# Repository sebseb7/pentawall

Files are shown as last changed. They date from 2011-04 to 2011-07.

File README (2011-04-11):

************
* pentawall
************

This project aims to build a full-RGB LED-wall with a resolution of at least 15x15 pixels. 

This is done using stackable 5x1 LED modules. (pentawall because its 5 LEDs per module)

I produced 50 of these modules and finished a 15x16 Wall as you can see here: http://vimeo.com/21198058 and http://vimeo.com/21123365

*****
* technical overview
*****

LED MODULE
==========

each module consists of 
- 5 LEDs ( Osram LRTB G6TG )
- 1 LED controller ( Textas Instruments TLC5941 ) 
- 1 microcontroller ( Atmel ATMEGA168pa ) 

The TLC5941 is a 16-channel, constant-current sink, LED driver. Here only 15 channels are in use (5 LEDs * 3 colors).
Each channel has an individually adjustable 4096-step grayscale PWM brightness control and a 64-step constant-current sink (dot correction).
Both grayscale control and dot correction are accessible via a serial interface (SPI).
For grayscale control the atmega has to feed in 24 bytes of data (16 * 12 bit).

The microcontroller receives its data via an i2c bus.

MASTER MODULE
=============

consists of
- atmega644p
- ft232rl

the master module recives data via USB and feeds that data to the led modules via i2c bus.
Using this master any PC with USB can control the LED wall. If you have i2c on you computer you dont need this module.

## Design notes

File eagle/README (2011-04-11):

this folder contains the schematics and board layout files for the hardware

5led.* the LED Module
ledmaster.* the master module (i2c to usb bridge)

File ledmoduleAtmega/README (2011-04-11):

This is the Code for the microcontroller on the X5LED board.

it acts as a i2c slave and receives data over the i2c bus to set led channel brightness

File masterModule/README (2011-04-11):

This is the Code for the microcontroller on the master module

it acts as a uart -> i2c bridge to access the ledmodules via uart

with an ftdi it can be connected to usb

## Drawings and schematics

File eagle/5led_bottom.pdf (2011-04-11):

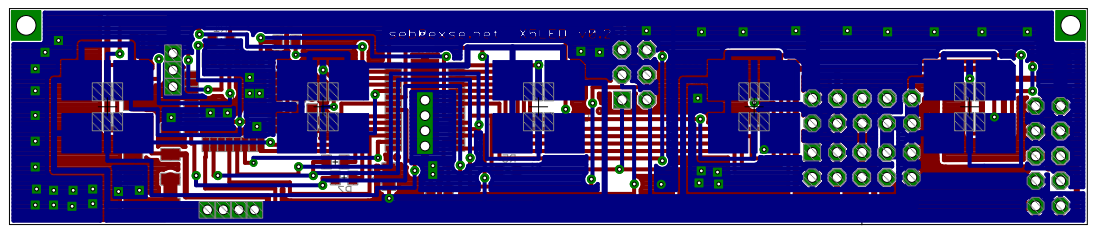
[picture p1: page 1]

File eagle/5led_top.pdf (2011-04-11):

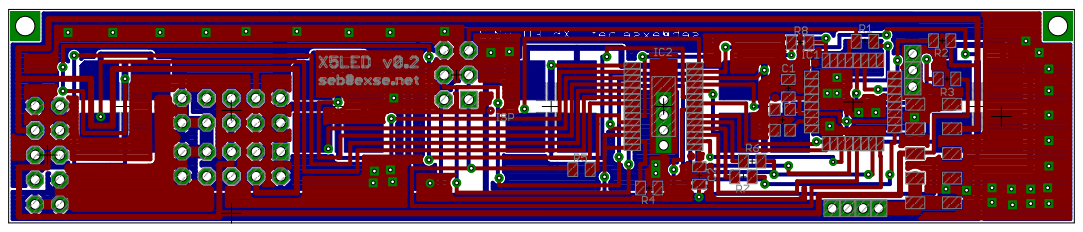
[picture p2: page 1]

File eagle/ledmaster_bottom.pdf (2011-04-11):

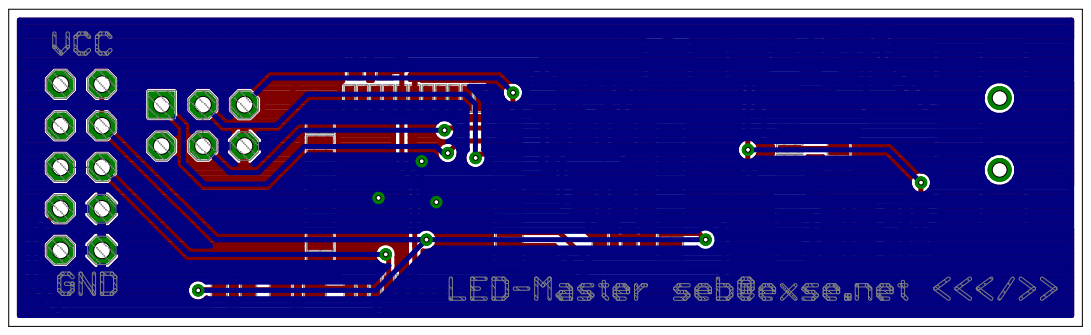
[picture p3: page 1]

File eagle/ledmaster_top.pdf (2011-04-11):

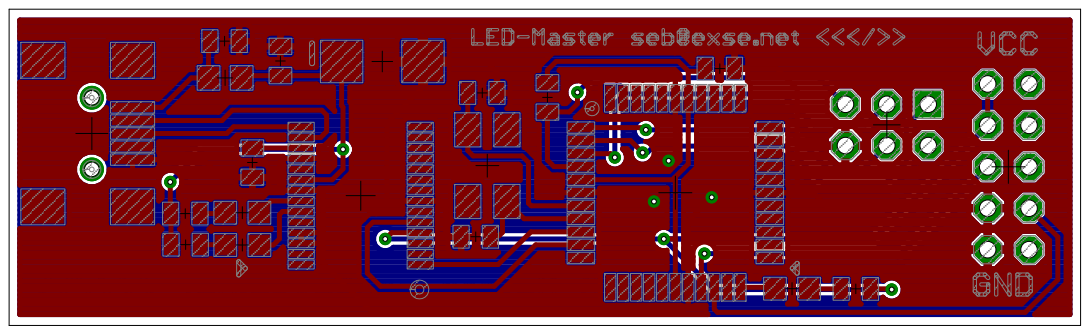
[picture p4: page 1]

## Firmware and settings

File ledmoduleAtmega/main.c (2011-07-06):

#include <inttypes.h>
#include <avr/io.h>
#include <avr/interrupt.h>
#include <avr/eeprom.h>
#include <util/delay.h>

#include "main.h"
#include "timer.h"
#include "TWI_Slave.h"
#include "leds.h"
#include "spi.h"


// BLANC == PB2
// XLAT  == PB1
// SCLK == SCK/PB5
// SIN == MOSI/PB3
// MODE == PD5
// XERR == PD2
// SOUT == MISO/PB4
// GSCLK == PB0


int main (void)
{

	// set mosi/sck output
	DDRB |= (1<<DDB5)|(1<<DDB3)|(1<<DDB2);
	
	//latch output
	DDRB |= (1<<DDB1);
	//blank output
	DDRD |= (1<<DDD7);
	//mode output
	DDRD |= (1<<DDD5);

	// latch off
	PORTB &= ~(1<<PORTB1);
	// blank = high (all off)
	PORTD |= (1<<PORTD7);
	// mode = ground
	PORTD &= ~(1<<PORTD5);


	SPI_Init();
	TIMER1_Init();
	sei ();
	


	SetDC(0,63,63,63);
	SetLed(0,0,0,0);
	
	// address
	uint8_t addr = ADDR;
	
	//inital strobe for address identifiction
	for(uint8_t j=0;j < (addr-1);j++)
	{
		for(uint8_t i = 0;i<5;i++)
		{
			if(i!=0) SetLed(i,0,0,0);
			SetLed(i+1,0,0,0);
			_delay_ms(10);
		}
	}
	for(uint8_t i = 0;i<5;i++)
	{
		if(i!=0) SetLed(i,0,0,0);
		SetLed(i+1,255,255,255);
		_delay_ms(10);
	}
	SetLed(0,0,0,0);
	
	
	// all slaves listen to addr 2
	TWIS_Init(2, 210526);
	
	uint8_t pixel = 0;
	uint8_t module  = 0;

	uint8_t	TWIS_ResonseType;

	uint8_t temp_r = 0;
	uint8_t temp_g = 0;
	uint8_t temp_b = 0;

	uint8_t led_1_r = 0;
	uint8_t led_1_g = 0;
	uint8_t led_1_b = 0;
	uint8_t led_2_r = 0;
	uint8_t led_2_g = 0;
	uint8_t led_2_b = 0;
	uint8_t led_3_r = 0;
	uint8_t led_3_g = 0;
	uint8_t led_3_b = 0;
	uint8_t led_4_r = 0;
	uint8_t led_4_g = 0;
	uint8_t led_4_b = 0;
	uint8_t led_5_r = 0;
	uint8_t led_5_g = 0;
	uint8_t led_5_b = 0;

						
	while(1)
	{						
		if (TWIS_ResonseRequired (&TWIS_ResonseType))
		{
			switch (TWIS_ResonseType)
			{
				case TWIS_ReadBytes:
	
					module = TWIS_ReadAck();

					if(module >= 254)
					{
						for(uint8_t n=0;n<3;n++)
						{
							for(uint8_t i=0;i<5;i++)
							{
								for(uint8_t m=0;m<16;m++)
								{
									temp_r = TWIS_ReadAck();
									temp_g = TWIS_ReadAck();
									temp_b = TWIS_ReadAck();

			
									if( (ADDR-1) == n*16+m )
									{

										if(i == 0)
										{
											led_1_r = temp_r;
											led_1_g = temp_g;
											led_1_b = temp_b;
										}
										if(i == 1)
										{
											led_2_r = temp_r;
											led_2_g = temp_g;
											led_2_b = temp_b;
										}
										if(i == 2)
										{
											led_3_r = temp_r;
											led_3_g = temp_g;
											led_3_b = temp_b;
										}
										if(i == 3)
										{
											led_4_r = temp_r;
											led_4_g = temp_g;
											led_4_b = temp_b;
										}
										if(i == 4)
										{
											led_5_r = temp_r;
											led_5_g = temp_g;
											led_5_b = temp_b;
										}
									}
								}
							}	
						}

						TWIS_ReadNack();
						TWIS_Stop();

						if(module == 255)
						{
							SetLed(1,led_1_r,led_1_g,led_1_b);
							SetLed(2,led_2_r,led_2_g,led_2_b);
							SetLed(3,led_3_r,led_3_g,led_3_b);
							SetLed(4,led_4_r,led_4_g,led_4_b);
							SetLed(5,led_5_r,led_5_g,led_5_b);
						}

						if(module == 254)
						{
							SetDC(1,led_1_r,led_1_g,led_1_b);
							SetDC(2,led_2_r,led_2_g,led_2_b);
							SetDC(3,led_3_r,led_3_g,led_3_b);
							SetDC(4,led_4_r,led_4_g,led_4_b);
							SetDC(5,led_5_r,led_5_g,led_5_b);
						}

					}
					else
					{
						pixel = TWIS_ReadAck();
						uint8_t red = TWIS_ReadAck();
						uint8_t green = TWIS_ReadAck();
						uint8_t blue = TWIS_ReadNack();
						TWIS_Stop();

						if((module == ADDR)||(module == 0))
						{
								SetLed(pixel,red,green,blue);
						}
					}					
					
					break;
			}
		}
	}
}

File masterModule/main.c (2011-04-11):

#include <inttypes.h>
#include <avr/io.h>
#include <avr/interrupt.h>
#include <util/delay.h>

#include "main.h"
#include "usart.h"
#include "TWI_Master.h"


/*

ideas to optimize the code:

- not more uart buffer, directly write to two full-frame buffers and 2 single LED buffers
- do the parsing in the Usart ISR (keep in mind that the ISR should be as short as possible)
- set xoff if one fullframe/led buffer is full and the second one is 50% filled
- the while loop then only polls buffer status 


think about: can eleminate the full-frame buffer by directly writing to i2c?

*/


uint8_t framebuffer[720];
uint8_t ledbuffer[5];


void SetLed(void)
{
	if (!TWIM_Start (2, TWIM_WRITE))
	{
		TWIM_Stop ();
	}
	else
	{
		TWIM_Write(ledbuffer[0]);
		TWIM_Write(ledbuffer[1]);
		TWIM_Write(ledbuffer[2]);
		TWIM_Write(ledbuffer[3]);
		TWIM_Write(ledbuffer[4]);
		TWIM_Stop ();
	}
}


void SetFrame(void)
{
	if (!TWIM_Start (2, TWIM_WRITE))
	{
		TWIM_Stop ();
	}
	else
	{
		TWIM_Write (255);
					
		for(uint8_t m = 0;m<48;m++)
		{
			uint16_t midx = m*15;
			
			for(uint8_t n = 0;n<15;n++)
			{
				TWIM_Write(framebuffer[midx+n]);
			}			
		}
		TWIM_Write (255);
		TWIM_Stop ();
	}
}



int main (void)
{

	// overflow led
	DDRC |= (1<<DDC3);

	USART_Init ();
	sei ();


	TWIM_Init (200000);

	_delay_ms(500);


	// fill wall with green 
	ledbuffer[2]=55;
	ledbuffer[3]=105;
	ledbuffer[4]=0;
	for(uint8_t p = 1;p<49;p++)
	{
		ledbuffer[0]=p;
		
		ledbuffer[1]=1;
		SetLed();
		_delay_ms(20);
		ledbuffer[1]=2;
		SetLed();
		_delay_ms(20);
		ledbuffer[1]=3;
		SetLed();
		_delay_ms(20);
		ledbuffer[1]=4;
		SetLed();
		_delay_ms(20);
		ledbuffer[1]=5;
		SetLed();
		_delay_ms(20);
	}

	
	uint8_t mode = 0;
	
	uint8_t data = 0;
	uint8_t escape = 0;
	uint16_t idx = 0;
	
	while(1)
	{
		while (uart_getc_nb(&data))
		{

			
			if(data == 0x42)
			{
				mode = 1;
				continue;
			}
			if(data == 0x23)
			{
				mode = 2;
				idx = 0;
				continue;
			}
			if(data == 0x65)
			{
				escape = 1;
				continue;
			}


			if(escape == 1)
			{
				escape = 0;
				if(data == 0x01)
				{
					data = 0x23;
				}
				else if(data == 0x02)
				{
					data = 0x42;
				}
				else if(data == 0x03)
				{
					data = 0x65;
				}
				else if(data == 0x04)
				{
					data = 0x66;
				}
			}
			
		
			if(mode == 1)
			{
				ledbuffer[idx]=data;
				idx++;

				if(idx == 5)
				{
					SetLed();
					mode = 0;
					idx = 0;
				}
			}
			else if(mode == 2)
			{
				framebuffer[idx]=data;
				idx++;	
				

				if(idx == 720)
				{
					SetFrame();
					mode = 0;
					idx = 0;
				}
			}
		}
	}
}

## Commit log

2011-03-19 changed from i2c addressing to in band addressing / multiplexing and added full frame updates
2011-04-03 use frame mode
2011-04-04 state stuff into LEDWall.runAnimation
2011-04-04 LEDWall: Word = Word8
2011-04-13 i2c slow down
2011-05-08 It works and prints stuff. Yet only pixel update...
2011-05-16 fixed pull request merge: conditional "use" of IO::Socket::INET6
